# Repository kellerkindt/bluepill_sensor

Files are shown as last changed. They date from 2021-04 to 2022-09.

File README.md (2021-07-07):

# Bluepill Ethernet Sensor Extension Board

This project is about an extension board for the Bluepill (based on stm32f103) I develop in my spare time.
I use this board to monitor the temperature at various places in my house, the CO2 concentration at my desktop as well as my energy consumption.
All values are polled through the network (UDP) by munin. You can even watch some live readings [here](https://home.watzko.de).
The board is designed to be stacked on top of another expansion PCB and provides the following functionality itself:

 - an ethernet connection via W5500
 - an OneWire connector (3.3v, GND, Data)
 - an EEPROM socket (AT93C46W via DIP or SOIC)
 - temperature sensor (LM75 SOIC)
 - a (factory reset) button
 - 2x status LEDs
    - with jumpers to disconnect them from the RTC pins (PC14 & PC15)
 - 8x LEDs via on-board GPIO-I2C-Expander PCF8574 (SOIC)
 - I2C-2 connector for further frontend expansion (3.3v, GND, SDA and SCL)

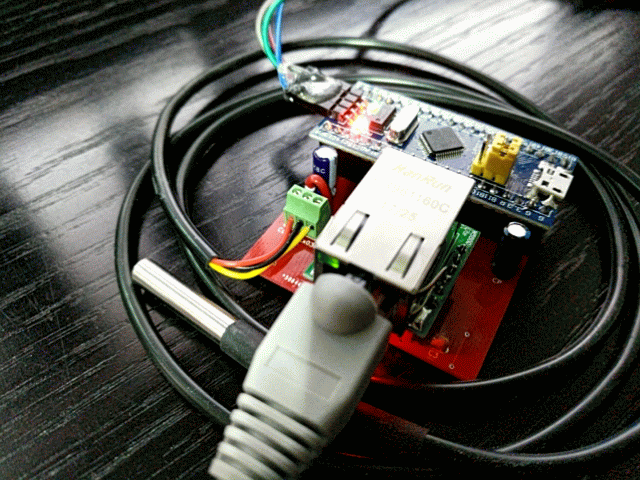
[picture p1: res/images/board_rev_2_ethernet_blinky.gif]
 \
(Board rev 2 connected to ethernet and with an OneWire temperature sensor)

### Pinout

On the top and bottom borders the board provides the same pin-layout as the Bluepill itself.
The top row is directly connected to the Bluepill and no pin is used by the board.
Although all pins of the bottom row are used by components on the board, they are routed through nonetheless
(keep in mind that the 2x2 jumper pins can disconnect PC14 & PC15 from the board entirely - including from the bottom pins). 

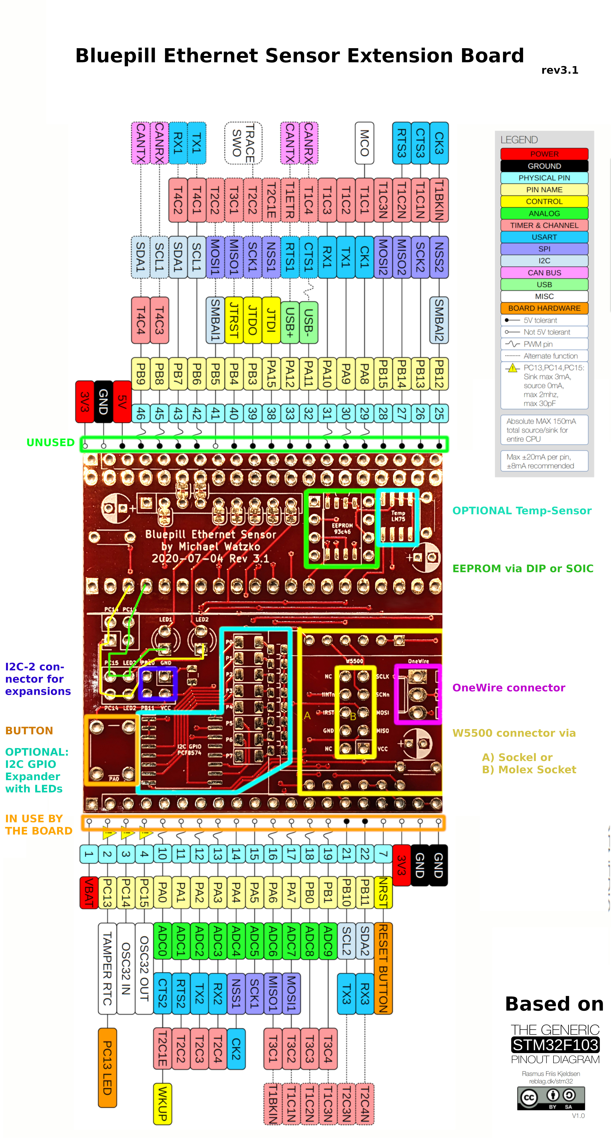
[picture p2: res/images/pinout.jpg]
Pinout


## Gallery

### Animated assembly of board rev 3.1

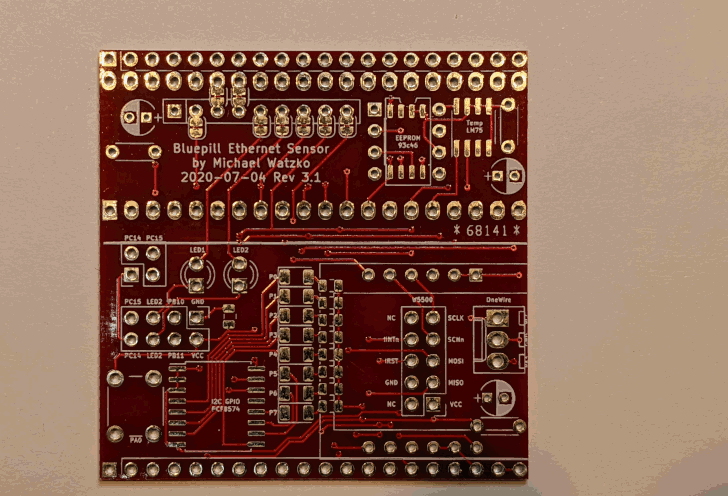
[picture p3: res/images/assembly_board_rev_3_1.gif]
Animaged assembly of board rev 3-1


### CO2 expansion

todo

### GPIO LED Demo

todo

#### License

<sup>
Licensed under either of <a href="LICENSE-APACHE">Apache License, Version
2.0</a> or <a href="LICENSE-MIT">MIT license</a> at your option.
</sup>

<br>

<sub>
Unless you explicitly state otherwise, any contribution intentionally submitted
for inclusion in this crate by you, as defined in the Apache-2.0 license, shall
be dual licensed as above, without any additional terms or conditions.
</sub>

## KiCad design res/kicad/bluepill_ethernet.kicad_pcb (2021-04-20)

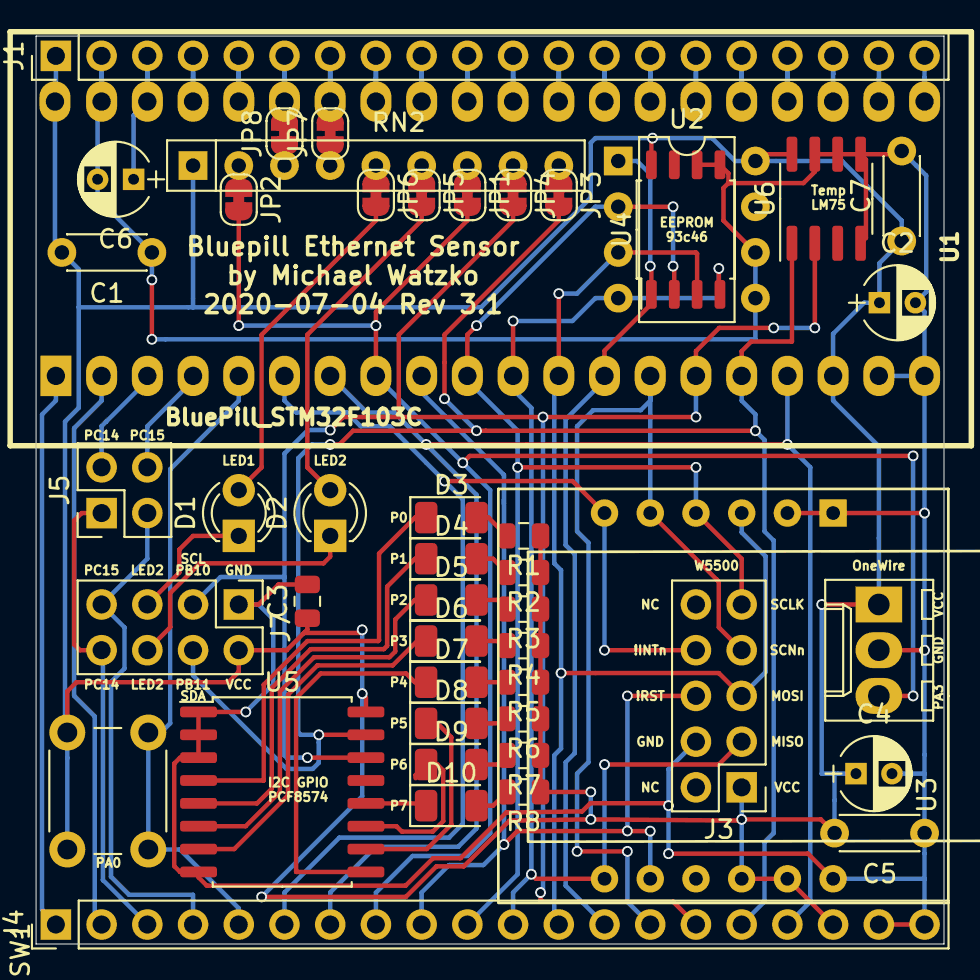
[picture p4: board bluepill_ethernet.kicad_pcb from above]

Board: 2 copper layers, 50.4 x 50.4 mm, 47 parts (0 on the bottom side), 66 nets.

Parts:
C1, C5, C7: C; C_Disc_D4.3mm_W1.9mm_P5.00mm
C2, C4, C6: CP; CP_Radial_D4.0mm_P2.00mm
C3: C; C_0805_2012Metric
D1, D2: LED; LED_D3.0mm
D3, D4, D5, D6, D7, D8, D9, D10: LED; LED_1206_3216Metric
J1, J4: HEADER-1x20; Pin_Header_Straight_1x20_Pitch2.54mm
J2: Conn_01x03; Molex_KK-6410-03_03x2.54mm_Straight
J3: Conn_02x05_Odd_Even; Pin_Header_Straight_2x05_Pitch2.54mm
J5: Conn_02x02_Odd_Even; PinHeader_2x02_P2.54mm_Vertical
J7: Conn_02x04_Odd_Even; PinHeader_2x04_P2.54mm_Vertical
JP1, JP2, JP3, JP4, JP5, JP6, JP7, JP8: SolderJumper_2_Bridged; SolderJumper-2_P1.3mm_Bridged_RoundedPad1.0x1.5mm
R1, R2, R3, R4, R5, R6, R7, R8: R; R_0805_2012Metric
RN2: 4,7k; R_Array_SIP9
SW1: SW_Push; SW_PUSH_6mm
U1: BluePill_STM32F103C
U2: 93C46; DIP-8_W7.62mm
U3: WIZ850io
U4: 93C46; SOIC-8_5.23x5.23mm_P1.27mm
U5: PCF8574A; SOIC-16W_7.5x10.3mm_P1.27mm
U6: LM75B; SOIC-8_3.9x4.9mm_P1.27mm

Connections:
GND: C1.1, C2.2, C3.2, C4.2, C5.1, C6.2, C7.2, J1.2, J2.2, J3.4, J4.19, J4.20, J7.1, U1.19, U1.20, U1.39, U2.5, U2.6, U3.1, U3.2, U3.12, U4.5, U4.6, U5.1, U5.2, U5.3, U5.8, U6.4, U6.5, U6.6, U6.7
unnamed: C6.1, J1.3, U1.38
unnamed: D1.1, J7.5
unnamed: D2.1, J7.6
unnamed: D3.1, U5.4
unnamed: D3.2, R1.2
unnamed: D4.1, U5.5
unnamed: D4.2, R2.2
unnamed: D5.1, U5.6
unnamed: D5.2, R3.2
unnamed: D6.1, U5.7
unnamed: D6.2, R4.2
unnamed: D7.1, U5.9
unnamed: D7.2, R5.2
unnamed: D8.1, U5.10
unnamed: D8.2, R6.2
unnamed: D9.1, U5.11
unnamed: D9.2, R7.2
unnamed: D10.1, U5.12
unnamed: D10.2, R8.2
unnamed: J1.4, U1.37
unnamed: J1.5, U1.36
unnamed: J1.6, JP8.2, U1.35
unnamed: J1.7, JP7.2, U1.34
unnamed: J1.8, U1.33
unnamed: J1.9, U1.32
unnamed: J1.10, U1.31
unnamed: J1.11, U1.30
unnamed: J1.12, U1.29
unnamed: J1.13, U1.28
unnamed: J1.14, U1.27
unnamed: J1.15, U1.26
unnamed: J1.16, U1.25
unnamed: J1.17, U1.24
unnamed: J1.18, U1.23
unnamed: J1.19, U1.22
unnamed: J1.20, U1.21
unnamed: J2.3, J4.8, JP1.2, JP2.2, U1.8
unnamed: J3.3, J4.11, U1.11, U2.4, U3.7, U4.4
unnamed: J3.5, J4.12, U1.12, U2.3, U3.3, U4.3
unnamed: J3.6, J4.9, U1.9, U3.8
unnamed: J3.7, J4.14, U1.14, U3.5
unnamed: J3.8, J4.6, U1.6, U3.6
unnamed: J3.9, J4.10, U1.10, U2.2, U3.4, U4.2
unnamed: J4.1, U1.1
unnamed: J4.2, U1.2
unnamed: J4.3, J5.1, J7.8
unnamed: J4.4, J5.3, J7.7
unnamed: J4.5, SW1.2, U1.5
unnamed: J4.13, U1.13, U2.1, U4.1
unnamed: J4.7, J4.17, U1.7, U1.17
unnamed: J5.2, U1.3
unnamed: J5.4, U1.4
unnamed: JP1.1, RN2.7
unnamed: JP2.1, RN2.2
unnamed: JP3.1, RN2.9
unnamed: JP4.1, RN2.8
unnamed: JP5.1, RN2.6
unnamed: JP6.1, RN2.5
unnamed: JP7.1, RN2.4
unnamed: JP8.1, RN2.3
VCC: C1.2, C2.1, C3.1, C4.1, C5.2, C7.1, J1.1, J2.1, J3.1, J4.18, J7.2, R1.1, R2.1, R3.1, R4.1, R5.1, R6.1, R7.1, R8.1, RN2.1, SW1.1, U1.18, U1.40, U2.8, U3.10, U3.11, U4.8, U5.16, U6.8
dled1: D1.2, JP6.2
dled2: D2.2, JP5.2
i2c1c: J4.15, J7.3, JP4.2, U1.15, U5.14, U6.2
i2c1d: J4.16, J7.4, JP3.2, U1.16, U5.15, U6.1

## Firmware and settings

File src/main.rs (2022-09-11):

#![no_std]
#![no_main]
#![deny(broken_intra_doc_links)]

#[macro_use(entry)]
extern crate cortex_m_rt;

//extern crate panic_abort;
//extern crate panic_halt;
use panic_persist as _;

//#[macro_use(block_while)]
#[macro_use(block)]
extern crate nb;

#[macro_use]
extern crate sensor_common;

#[macro_use]
mod nb_ext;

#[macro_use]
mod props;

// mod am2302;
mod ds93c46;
mod io_utils;
mod module;
mod platform;
mod system;
// mod sht1x;
mod cnf;

#[entry]
fn main() -> ! {
    platform::unwrap_builder().run_with_module::<crate::module::FeaturedModule>()
}

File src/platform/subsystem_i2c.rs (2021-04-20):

use embedded_hal::blocking::i2c;
use lm75::{Error as Lm75Error, Lm75, SlaveAddr};
use nb::Error as NbError;
use stm32f1xx_hal::gpio::gpiob::{PB10, PB11};
use stm32f1xx_hal::gpio::{Alternate, OpenDrain};
use stm32f1xx_hal::i2c::{BlockingI2c, Error as I2cError};

pub struct I2cBus {
    pub(super) i2c: BlockingI2c<
        stm32f1xx_hal::pac::I2C2,
        (PB10<Alternate<OpenDrain>>, PB11<Alternate<OpenDrain>>),
    >,
}

impl I2cBus {
    #[allow(unused)]
    pub fn init(&mut self) {
        #[cfg(feature = "board-rev-3-1")]
        let _ = self.set_expander_gpio(0xFF);
    }

    #[allow(unused)]
    pub fn read_temperature(&mut self) -> Result<f32, Lm75Error<NbError<I2cError>>> {
        Lm75::new(I2cRef(&mut self.i2c), SlaveAddr::Default).read_temperature()
    }

    #[allow(unused)]
    pub fn read_temperature_blocking(&mut self) -> Result<f32, Lm75Error<I2cError>> {
        loop {
            match self.read_temperature() {
                Ok(v) => break Ok(v),
                Err(lm75::Error::InvalidInputData) => break Err(lm75::Error::InvalidInputData),
                Err(lm75::Error::I2C(nb::Error::Other(e))) => break Err(lm75::Error::I2C(e)),
                Err(lm75::Error::I2C(nb::Error::WouldBlock)) => continue,
            }
        }
    }

    #[allow(unused)]
    #[cfg(feature = "board-rev-3-1")]
    pub fn set_expander_gpio(
        &mut self,
        status: u8,
    ) -> Result<(), pcf857x::Error<nb::Error<I2cError>>> {
        pcf857x::Pcf8574::new(I2cRef(&mut self.i2c), pcf857x::SlaveAddr::Default).set(status)
    }

    #[allow(unused)]
    #[cfg(feature = "board-rev-3-1")]
    pub fn set_expander_gpio_blocking(
        &mut self,
        status: u8,
    ) -> Result<(), pcf857x::Error<I2cError>> {
        loop {
            match self.set_expander_gpio(status) {
                Ok(v) => break Ok(v),
                Err(pcf857x::Error::I2C(nb::Error::WouldBlock)) => continue,
                Err(pcf857x::Error::I2C(nb::Error::Other(e))) => break Err(pcf857x::Error::I2C(e)),
                Err(pcf857x::Error::CouldNotAcquireDevice) => {
                    break Err(pcf857x::Error::CouldNotAcquireDevice)
                }
                Err(pcf857x::Error::InvalidInputData) => {
                    break Err(pcf857x::Error::InvalidInputData)
                }
            }
        }
    }
}

pub struct I2cRef<'a, I: i2c::Write>(&'a mut I);

impl<I: i2c::Write> i2c::Write for I2cRef<'_, I> {
    type Error = I::Error;

    #[inline]
    fn write(&mut self, addr: u8, bytes: &[u8]) -> Result<(), Self::Error> {
        self.0.write(addr, bytes)
    }
}

impl<I: i2c::Write> i2c::Read for I2cRef<'_, I>
where
    I: i2c::Read,
{
    type Error = <I as i2c::Read>::Error;

    #[inline]
    fn read(&mut self, address: u8, buffer: &mut [u8]) -> Result<(), Self::Error> {
        self.0.read(address, buffer)
    }
}

impl<I: i2c::Write> i2c::WriteRead for I2cRef<'_, I>
where
    I: i2c::WriteRead,
{
    type Error = <I as i2c::WriteRead>::Error;

    #[inline]
    fn write_read(
        &mut self,
        address: u8,
        bytes: &[u8],
        buffer: &mut [u8],
    ) -> Result<(), Self::Error> {
        self.0.write_read(address, bytes, buffer)
    }
}

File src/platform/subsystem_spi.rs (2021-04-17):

use crate::cnf::NetworkConfiguration;
use crate::ds93c46::DS93C46;
use crate::io_utils::OutputPinInfallible;
use crate::platform::SpiError;
use embedded_hal::blocking::delay::DelayMs;
use embedded_nal::UdpFullStack;
use embedded_nal::{SocketAddr, SocketAddrV4, UdpClientStack};
use stm32f1xx_hal::gpio::gpioa::*;
use stm32f1xx_hal::gpio::gpiob::*;
use stm32f1xx_hal::gpio::{Alternate, Floating, Input, Output, PushPull};
use stm32f1xx_hal::pac::SPI1;
use stm32f1xx_hal::spi::{Spi, Spi1NoRemap};
use w5500::bus::{FourWireError, FourWireRef};
use w5500::net::Ipv4Addr;
use w5500::udp::{UdpSocket, UdpSocketError};
use w5500::{
    ArpResponses, ConnectionType, Manual, OnPingRequest, OnWakeOnLan, UninitializedDevice,
};
use w5500::{DeviceRefMut, InactiveDevice};

pub struct SpiBus {
    /// W5500 interrupt pin
    #[allow(unused)]
    #[cfg(feature = "board-rev-2")]
    pub(super) w5500_intr: PB10<Input<Floating>>,
    #[allow(unused)]
    #[cfg(not(feature = "board-rev-2"))]
    pub(super) w5500_intr: PA1<Input<Floating>>,

    //pub(super) w5500: W5500<PB1<Output<PushPull>>>,
    pub(super) w5500: Option<InactiveDevice<w5500::Manual>>,
    pub(super) w5500_cs: PB1<Output<PushPull>>,

    /// EEPROM for configuration
    pub(super) ds93c46: DS93C46<PB0<Output<PushPull>>>,

    pub(super) spi: Spi<
        SPI1,
        Spi1NoRemap,
        (
            PA5<Alternate<PushPull>>,
            PA6<Input<Floating>>,
            PA7<Alternate<PushPull>>,
        ),
        u8,
    >,

    /// Low-Active pin to restart the W5500
    pub(super) w5500_reset: PA4<Output<PushPull>>,
}

impl SpiBus {
    pub fn init_network(
        &mut self,
        delay: &mut impl DelayMs<u16>,
        config: &NetworkConfiguration,
    ) -> Result<(), ()> {
        self.w5500 = None;

        // reset the network chip (timings are really generous)
        self.w5500_reset.set_low_infallible();
        delay.delay_ms(250_u16); // Datasheet 5.5.1 says 500_us to 1_ms (?)
        self.w5500_reset.set_high_infallible();
        delay.delay_ms(250_u16); // Datasheet says read RDY pin, the network chip needs some time to boot!

        self.w5500 = Some(
            UninitializedDevice::new(FourWireRef::new(&mut self.spi, &mut self.w5500_cs))
                .initialize_advanced(
                    config.mac,
                    config.ip,
                    config.gateway,
                    config.subnet,
                    w5500::Mode {
                        on_wake_on_lan: OnWakeOnLan::Ignore,
                        on_ping_request: OnPingRequest::Respond,
                        connection_type: ConnectionType::Ethernet,
                        arp_responses: ArpResponses::Cache,
                    },
                )
                .map_err(drop)?
                .deactivate()
                .1,
        );

        Ok(())
    }

    pub fn network(
        &mut self,
    ) -> Option<
        DeviceRefMut<
            FourWireRef<
                Spi<
                    SPI1,
                    Spi1NoRemap,
                    (
                        PA5<Alternate<PushPull>>,
                        PA6<Input<Floating>>,
                        PA7<Alternate<PushPull>>,
                    ),
                    u8,
                >,
                PB1<Output<PushPull>>,
            >,
            Manual,
        >,
    > {
        Some(
            self.w5500
                .as_mut()?
                .activate_ref(FourWireRef::new(&mut self.spi, &mut self.w5500_cs)),
        )
    }

    pub fn network_send_udp_to(
        &mut self,
        ip: Ipv4Addr,
        port: u16,
        data: &[u8],
        socket: &mut UdpSocket,
    ) -> Result<(), SpiError> {
        if let Some(device) = self.w5500.as_mut() {
            block!(device
                .activate_ref(FourWireRef::new(&mut self.spi, &mut self.w5500_cs))
                .send_to(socket, SocketAddr::V4(SocketAddrV4::new(ip, port)), data))
            .map_err(|e| match e {
                UdpSocketError::NoMoreSockets
                | UdpSocketError::UnsupportedAddress
                | UdpSocketError::WriteTimeout => SpiError::ModeFault,
                UdpSocketError::Other(e) => match e {
                    FourWireError::TransferError(_)
                    | FourWireError::WriteError(_)
                    | FourWireError::ChipSelectError(_) => SpiError::ModeFault,
                },
            })
        } else {
            Err(SpiError::ModeFault)
        }
    }

    pub fn network_receive_udp(
        &mut self,
        buffer: &mut [u8],
        socket: &mut UdpSocket,
    ) -> Result<Option<(Ipv4Addr, u16, usize)>, SpiError> {
        if let Some(device) = self.w5500.as_mut() {
            return match device
                .activate_ref(FourWireRef::new(&mut self.spi, &mut self.w5500_cs))
                .receive(socket, buffer)
            {
                Ok((_, SocketAddr::V6(_))) => unreachable!(),
                Ok((len, SocketAddr::V4(v4))) => Ok(Some((*v4.ip(), v4.port(), len))),
                Err(nb::Error::WouldBlock) => Ok(None),
                Err(nb::Error::Other(e)) => Err(match e {
                    UdpSocketError::NoMoreSockets
                    | UdpSocketError::UnsupportedAddress
                    | UdpSocketError::WriteTimeout => SpiError::ModeFault,
                    UdpSocketError::Other(e) => match e {
                        FourWireError::TransferError(_)
                        | FourWireError::WriteError(_)
                        | FourWireError::ChipSelectError(_) => SpiError::ModeFault,
                    },
                }),
            };
        } else {
            Ok(None)
        }
    }
}

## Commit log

2018-02-15 Flash + write! to stdout works via debug.sh + server.sh, LED blinking does not work
    [main.rs]
2018-02-16 LED blinks
2018-02-17 OneWire implementation through stm32f103xx_hal
2018-02-17 Clenaup + Update to latest OneWire implementation with patched stm32f103xx_hal (OpenDrain patch)
2018-02-18 Fix wrong compile target, does now find device via onewire
    [main.rs]
2018-03-10 Can transmit temperature via UDP packet
2018-03-11 Processing and answering very basic Request (sensor_common)
2018-03-30 Update code for custom pcb (including eeprom + self reset)
    [main.rs]
2018-03-30 W5500 no longer consumes SPI
    [main.rs]
2018-04-01 Add draft kicad files
    [bluepill_ethernet-2018-03-30-21-34-15.sch, bluepill_ethernet.kicad_pcb, bluepill_ethernet.sch]
2018-04-01 Current state does not respond, what is going on
2018-04-24 Add revision information for kicad circuit (rev1)
    [bluepill_ethernet.kicad_pcb, bluepill_ethernet.sch]
2018-04-24 Add button to kicad circuit for 'factory reset' the configuration (delete eeprom)
    [bluepill_ethernet.kicad_pcb, bluepill_ethernet.sch]
2018-05-31 Revision 2.0
    [bluepill_ethernet.kicad_pcb, bluepill_ethernet.sch]
2018-06-05 Fix production issues (also add molex pin for other W5500 boards)
    [bluepill_ethernet.kicad_pcb, bluepill_ethernet.sch]
2018-06-08 Update to latest rust / stm32f103xx-hal changes
2018-08-05 Include AM2302, fix it and use MonoTimer (to be replaced by CountDown-timer)
    [main.rs]
2018-08-08 Version 0.3.4: allow on right side on bluepill (below 3,3v/GND/5v + 2xI2C) to plug in up to 13 AM2302 sensors via custom read 0-12
2018-08-26 Version 0.3.6: Fix RetrieveDeviceInformation error causing operlap in returned values
    [main.rs, platform.rs]
2018-09-01 Version 0.2.3: Add workaround for MonoTimer, add support for multiple OneWire busses, reduce Am2302 pins by two (keep CAN free)
    [main.rs, platform.rs]
2018-09-01 Dont fail to collect onewire values if one bus is erronous
    [main.rs]
2018-09-01 Version 0.3.9: 3s press on button causes NetworkConfiguration reset to default (all 3 leds turn on)
    [main.rs, platform.rs]
2018-09-02 Add padding byte in device information
2018-09-02 Remove kicad backup files
    [bluepill_ethernet-2018-03-30-21-34-15.sch]
2018-09-02 Add kicad rescue files
2018-09-02 Fix of compiler warnings
    [ds93c46.rs, platform.rs]
2018-09-02 Fix compiler warnings, dont use hack for DWT anymore, instead use patched MonoTimer, show udp error on yellow LED
    [main.rs]
2018-12-08 Remove direct dependency on stm32f103xx
2018-12-11 Use stm32f103 from git master
2019-02-03 Add new I2C bus support with write_read
2019-02-12 Add basic uart communication, update to w5500 v0.2.0 (socket-refactor/state update)
2019-03-20 Can read CO2 sensor (requires actual power supply!)
2020-05-23 Update to edition 2018 and latest stm32f1xx-hal
2020-05-24 Fix uptime not increasing, 'async' freq measurement
    [main.rs, platform.rs]
2020-05-30 The great refactoring: make it more modular, throw out currently unused code
2020-05-30 Cleanup, re-add custom-read 251-254, fix unused time in LTFM::value
    [ds93c46.rs, ecm.rs, main.rs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]
2020-05-31 Move the status led into System
2020-06-16 board revision 3 alpha 1
    [bluepill_ethernet.kicad_pcb, bluepill_ethernet.sch]
2020-06-16 Ignore kicad backup files
2020-06-17 Board Rev 3.0
    [bluepill_ethernet.kicad_pcb, bluepill_ethernet.sch]
2020-06-22 Refactor to reduce main() as a single line + allow error dump retrieval
    [cnf.rs, ecm.rs, main.rs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]
2020-06-22 Provide FeaturedModule in DeviceInformation and improve feature flagging
2020-06-22 Version 0.4.0: Upgrade to rev 3.0 boards on default with fallback feature
2020-06-23 Version 0.4.1: Add IndependentWatchdog with 5s intervals and reset the network on error recovery
    [platform.rs]
2020-06-24 Move kicad libraries into this repository
2020-06-26 Add pumping system module
2020-06-28 Add basic PumpingState
2020-06-28 Add custom-read 200-204 to read pump+error state and counter level
    [ps.rs]
2020-06-30 Board rev 3.1: Fix invalid pcf8574 footprint (20->16 pins)
    [bluepill_ethernet.kicad_pcb, bluepill_ethernet.sch]
2020-07-01 Replace TSSOP packages with SOIC packages
    [bluepill_ethernet.kicad_pcb, bluepill_ethernet.sch]
2020-07-04 Move molex pins and w5500 into 2,54mm raster
    [bluepill_ethernet.kicad_pcb]
2020-08-09 Version 0.4.2: Add PreFail and Failure states which stops pumping at all eventually
    [mod.rs, ps.rs]
2020-08-09 Version 0.4.3: Allow multiple pre-fail passes with increased interval before failing eventually
    [ps.rs]
2020-11-21 Upgrade to stm32f1xx-hal 0.7.0
2021-03-23 Add env (currently only co2) module
2021-04-06 No longer default to a board-revision, require explicit feature flag
2021-04-06 Detect and re-init a crashed / re-bootet w5500 chip
    [platform.rs]
2021-04-17 Create subsystem i2c
2021-04-18 Add command line hint for china clones of stm32f103
2021-04-18 Add values for caps, resistotrs, ... for board rev 3.1
    [bluepill_ethernet.sch]
2021-04-20 Add SCL and SDA labels to the pin header
    [bluepill_ethernet.kicad_pcb]
2021-04-20 Fix board-rev handling and imports
    [platform.rs, subsystem_i2c.rs]
2021-07-07 Add properties to ElectricityMeter and dummy to nop + PumpingSystem
2021-07-17 Fix visibility if subsystem_i2c
    [platform.rs]
2022-03-13 Add pump state status string
2022-03-13 Add fifth pin to the LongTimeFreqMeasurement
2022-03-13 Fix range for fifth ltfm in em-module
    [em.rs]
2022-06-21 Add property accessors for PumpState module
2022-07-18 Remove RequestHandle body from PumpState
2022-07-18 Fix RetrieveProperty for longer paths
    [platform.rs]
2022-09-07 Use ListComponentResponder and RetrievePropertyResponder from sensor_common
2022-09-11 Use property_read_fn! and property_write_fn! macros from sensor_common
